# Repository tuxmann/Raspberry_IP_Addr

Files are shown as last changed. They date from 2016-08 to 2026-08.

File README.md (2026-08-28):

# Raspberry Pi IP Address Display

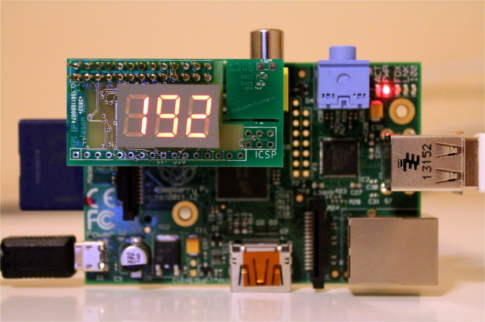
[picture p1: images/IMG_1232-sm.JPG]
Image of IP_Addr


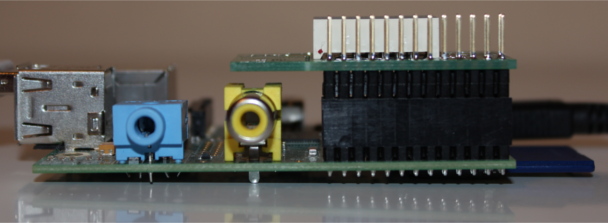
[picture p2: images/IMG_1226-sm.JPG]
Image of IP_Addr side


A hardware add-on that displays your Raspberry Pi's IP address on a 3-digit 7-segment LED display. Compatible with all Raspberry Pi models and other pin-compatible SBCs (Orange Pi, Banana Pi, Odroid, etc.).

## Quick Start

1. **Enable I2C and SPI:** `sudo raspi-config` → Interface Options
2. **Install:** `sudo apt install python3-smbus i2c-tools` (or `pip install smbus2`)
3. **Run:** `python3 hostip.py`
4. **Auto-start at boot:** `./deploy-to-pi.sh --install-service` (after deploying)

See **[docs/SETUP.md](docs/SETUP.md)** for the full setup guide, including ATtiny88 programming and the reset pin requirement.

## Hardware

- **Board:** ATtiny88 drives a 3-digit ELT-316 common-anode 7-segment display
- **Communication:** I2C at address 0x5A
- **Size:** Sits 0.6" (1.5cm) above the Pi; total height ~1" (2.5cm) with headers
- **Expansion:** P3 (left) and P4 (right) connectors bring out Port C & D (ADC, analog comparator, external interrupts)

## Features

- Power-on message ("rPI IP by JAY v1.1 GPL 3")
- Timeout message if no IP received within ~5 minutes
- Cycles through IP octets (e.g., 192 → 168 → 1 → 100)

## Climate node (DHT22, standalone)

The board can run **without a Pi** as a temperature/humidity display using a **DHT22** on header **P3 pin 1 (PC0)**.

- Firmware: [`climate-node-dht22/`](climate-node-dht22/)
- Setup, wiring, build, and flash: **[docs/CLIMATE_NODE.md](docs/CLIMATE_NODE.md)**

Shows °F (e.g. `78.3`) and humidity (e.g. `H38`), one sensor read every 6 seconds (3 s per value on the display). Optional photoresistor dimming on **P3 pin 2**; compile-time calibration offsets for temperature and humidity.

## Documentation

- [Setup Guide](docs/SETUP.md) — Pi IP display: installation, configuration, and flashing
- [Climate Node (DHT22)](docs/CLIMATE_NODE.md) — Standalone temp/humidity firmware
- [Releases](https://github.com/tuxmann/Raspberry_IP_Addr/releases) — Pre-built binaries and documents
- [Schematic](docs/Pi.IP.Addr.Schematic.pdf)

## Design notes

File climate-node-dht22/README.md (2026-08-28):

# climate-node-dht22

Standalone **ATtiny88** firmware for the Raspberry Pi IP Address board: read a **DHT22** and show **temperature** (°F) and **humidity** on the onboard 3-digit display—no Raspberry Pi required for normal operation.

**Full setup guide:** [docs/CLIMATE_NODE.md](../docs/CLIMATE_NODE.md)

## Quick reference

| Item | Value |
|---|---|
| DHT22 data pin | **PC0** — P3 pin 1 (U1 pin 23) |
| Ambient dim (optional) | **PC1** — P3 pin 2; or set `USE_PHOTOSENSOR 0` and `PWM_MANUAL` |
| Sample interval | 6 seconds (one bus transaction) |
| Display timing | 3 s temperature, then 3 s humidity per cycle |
| Build output | `bin/climate_node.hex` |
| DHT algorithm | Ported from [Adafruit DHT-sensor-library](https://github.com/adafruit/DHT-sensor-library) `DHT.cpp` |

## Wiring

- DHT22 **data** → P3 pin 1 (PC0)
- DHT22 **VCC** / **GND** → board power
- **4.7k–10k** pull-up: data → VCC
- Optional dimmer: **R1/R2** divider + LDR to **P3 pin 2** (PC1) — see [CLIMATE_NODE.md](../docs/CLIMATE_NODE.md)

Brightness is set in `src/ambient_dim.c`:

- `USE_PHOTOSENSOR 1` — LDR on PC1, sampled ~1 s (`ADC_BRIGHT` 200, `ADC_DARK` 450)
- `USE_PHOTOSENSOR 0` — ignore LDR; set `PWM_MANUAL` 0–255 (255 = full bright)

Calibration in `src/main.c` (whole display units):

- `TEMP_OFFSET` — added to displayed temperature (currently °F), e.g. `-2` makes `78.0` → `76.0`
- `HUMIDITY_OFFSET` — added to displayed %RH, e.g. `-5` makes `H38` → `H33`

## Build

```bash
make clean && make
```

### Debug: ambient ADC level + live dimming

Shows **raw ADC** or **PWM percent (0–100)** on the display. Switch with `DEBUG_SHOW_PWM_PCT` in `src/debug_brightness.c` (`1` = percent, `0` = raw ADC).

- `ADC_BRIGHT` — ADC at or below → PWM 255 (brightest)
- `ADC_DARK` — ADC at or above → PWM 20 (dimmes; tune `PWM_MIN`)

```bash
make debug
sudo make flash-debug
```

Cover the LDR: percent drops (dimmer). Shine light: percent rises toward **100**. Set `DEBUG_SHOW_PWM_PCT` to `0` to see raw ADC instead.

## Flash (on Raspberry Pi, board on GPIO for SPI programming)

```bash
sudo make flash
```

Slower ISP if needed: see [docs/CLIMATE_NODE.md](../docs/CLIMATE_NODE.md).

## Source layout

| File | Role |
|---|---|
| `src/main.c` | Main loop, calibration offsets, 6 s sample / 3 s per value |
| `src/debug_brightness.c` | Debug image: raw ADC or PWM % on display |
| `src/dht22.c` | DHT22 single-wire read (Adafruit-style timing) |
| `src/dht22.h` | Reading struct and API |
| `src/display_pwm.c` | Timer0 ISR PWM brightness for 7-seg multiplex |
| `src/ambient_dim.c` | Photoresistor ADC → PWM duty (optional hardware) |

## Third-party credit

DHT22 timing logic in `src/dht22.c` is derived from Adafruit’s **DHT-sensor-library** (MIT). See [github.com/adafruit/DHT-sensor-library](https://github.com/adafruit/DHT-sensor-library).

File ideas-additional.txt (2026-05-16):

Additional ideas that the daughter board can be used for.

Scrolling message — Reuse your power-on style messages; Pi sends which message index to show.
CPU load — Average load × 100 (e.g. 125 = 1.25) or “Idl” when idle.
RAM usage — Percent used (e.g. 67) or free MB.
CPU temperature — Pi sends CPU temp (e.g. 45, 52) over I2C; display shows “C45” or “52.” with decimal.
Disk usage — Root filesystem percent full (e.g. 42).
Wi‑Fi signal — RSSI as a number (e.g. -65 → “65” or “-65” if you allow minus).
Simple notifications — “Err”, “Ok”, “Run”, “Stp”, “Net”, “IP” for scripts or services.
Speedtest result — Download Mbps as 3 digits (e.g. 125).

Pi-hole stats — Queries today as hundreds (e.g. 523) or “dns” / “blk”.
Uptime — Days (e.g. 007) or hours (e.g. 123).
Countdown / timer — Pi sends remaining seconds; display counts down (e.g. 599 → 598…).
Clock — Hours and minutes as 3 digits (e.g. 143 = 1:43) or minutes:seconds.
Plex/streaming status — “Ply”, “Pau”, “0” when nothing playing.
VPN status — “On” / “Off” or tunnel number.
Hex/dec view — Show a value from the Pi in hex (e.g. 0x1A2) or decimal (e.g. 418).

With extra components 
BME280/DHT — Pi reads sensor, sends temp/humidity to display (e.g. 72° and 45% as “72” / “45” or “725”).
Button(s) on Port C/D — Cycle display mode (IP / temp / clock / message) or start/stop a timer.
Rotary encoder — Interrupts on Port D; show value or menu index (e.g. 001, 002).
Relay/GPIO status — Pi sends which outputs are on; display “1”, “2”, “12” or “On”/“Off”.
Distance (ultrasonic) — Pi talks to sensor, sends cm; display shows 0–999 cm.

Temperature sensor (e.g. thermistor/ADC) — P3/P4 ADC; ATtiny88 reads voltage, converts to °C/°F, shows on display (or Pi reads over I2C if you add that path).
Analog voltage monitor — ADC; show battery or supply voltage (e.g. 3.2 V as “3.2” or “320”).
Current sense — Current-sense amp to ADC; show mA or “0.5A” style reading.
Light level — LDR on ADC; display brightness level (0–99) or “LOW”/“HIG”.
Potentiometer — ADC; show 0–100 or use as volume/setpoint and display that.
PIR motion — Interrupt; show “On” when motion, “Off” or count of events.
Reed switch / door sensor — Interrupt; “OPn” / “Cld” or simple 0/1.
RTC (I2C) — Pi or ATtiny88 (if you add RTC on I2C) keeps time; display shows time without NTP when offline.
Multi-sensor dashboard — Button or timer cycles what’s shown: temp, humidity, light, IP, etc., with one sensor per “extra component” above.

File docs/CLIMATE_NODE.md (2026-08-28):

# Climate Node (DHT22) — Setup Guide

Standalone use of the Raspberry Pi IP Address board **without** a Raspberry Pi host: an ATtiny88 reads a **DHT22** sensor and shows **temperature** and **humidity** on the built-in 3-digit display.

Firmware lives in [`climate-node-dht22/`](../climate-node-dht22/).

## Hardware

| Connection | Detail |
|---|---|
| DHT22 data | **PC0** — **U1 pin 23**, header **P3 pin 1** |
| Ambient light (optional) | **PC1 (ADC1)** — **P3 pin 2** |
| DHT22 VCC / GND | Board power (see power section below) |
| Data pull-up | **4.7k–10k** from data to VCC (required) |

**Do not use** pins already used by the 7-segment display, I2C (SDA/SCL), SPI (ISP), or UART if you may add those interfaces later.

### Optional photoresistor dimming (P3 pin 2)

Divider from **VCC** to **GND** with tap to **PC1**:

```text
VCC ---- R1 ----+---- PC1 (P3 pin 2)
                |
                +---- R2 ---- GND
                |
                LDR (optional, to GND, parallel with R2)
```

- Install **R1** and **R2** on boards that use dimming.
- **Bright room** → lower ADC → brighter display. **Dark room** → higher ADC → dimmer display.
- In `src/ambient_dim.c`:
  - `USE_PHOTOSENSOR 1` — read LDR once per second (`ADC_BRIGHT` **200**, `ADC_DARK` **450**, same as debug).
  - `USE_PHOTOSENSOR 0` — no LDR; set `PWM_MANUAL` **0–255** (255 = full brightness).

Tune `ADC_BRIGHT`, `ADC_DARK`, `PWM_MIN`, and `PWM_MANUAL` in `src/ambient_dim.c`.

### Standalone power (no Pi)

- Feed **5 V** and ground from USB (or similar).
- Many builds tie **P1 pins 1, 2, and 4** as 5 V tie points and use **P1 ground pins** (e.g. 6, 9, 14, 20) for return.
- Confirm your board’s actual rail (3.3 V vs 5 V for the MCU) matches how you power the DHT22.

### Programming (Pi + SPI)

To **flash** firmware, stack the board on a Raspberry Pi with **SPI enabled** and use the same **linuxspi** wiring as the original IP-display project (reset **not** held to ground). See [SETUP.md](SETUP.md) §7.

## Display behavior

| Phase | Display | Duration |
|---|---|---|
| Power-up | `rdy` | 2 s |
| Each 6 s cycle | Temperature (°F), then humidity | 3 s each |
| Read failed (including disconnected sensor) | `Err` | Until next good read; replaces last values on screen |

**Temperature (°F)**

- Below 100 °F: one decimal (e.g. `78.3`)
- 100 °F and above: integer only (e.g. `104`)

**Humidity**

- `H` + two digits (e.g. `H38` for 38%)

**Calibration** (`src/main.c`):

- `TEMP_OFFSET` — whole degrees of the displayed scale (currently °F). Example: `-2` shows `76.0` instead of `78.0`.
- `HUMIDITY_OFFSET` — whole percent RH. Example: `-5` shows `H33` instead of `H38`.

Sensor is polled **once every 6 seconds** (`SAMPLE_PERIOD_MS` in `src/main.c`). Temperature and humidity each stay on screen for **3 seconds** (`SHOW_TEMP_MS`). DHT22 needs quiet time between reads; do not poll faster than about every 2 s.

**Brightness:** Timer0 ISR software PWM (`src/display_pwm.c`). With `USE_PHOTOSENSOR 1`, duty follows ambient ADC (**200** bright → **450** dark) about once per second. With `USE_PHOTOSENSOR 0`, duty is fixed at `PWM_MANUAL`.

## DHT driver

Bit timing is ported from **[Adafruit DHT-sensor-library](https://github.com/adafruit/DHT-sensor-library)** (`DHT.cpp`). The AVR driver is in `src/dht22.c` (cycle-count pulse compare, same algorithm).

## Build and flash

### On the Raspberry Pi (recommended)

```bash
cd ~/Raspberry_IP_Addr/climate-node-dht22
make clean && make
sudo make flash
```

If avrdude reports *device not responding*, use a slower ISP clock:

```bash
sudo avrdude -c linuxspi -P /dev/spidev0.0:/dev/gpiochip0 -p t88 -B 125kHz \
  -U flash:w:bin/climate_node.hex:i
```

Or slower:

```bash
sudo avrdude -c linuxspi -P /dev/spidev0.0:/dev/gpiochip0 -p t88 -B 50kHz \
  -U flash:w:bin/climate_node.hex:i
```

### On a development PC (compile only)

```bash
sudo apt install gcc-avr avr-libc
cd climate-node-dht22
make
```

Copy `bin/climate_node.hex` to the Pi and flash with `sudo make flash` or the `avrdude` line above.

### Deploy source from your PC

```bash
rsync -avz --exclude '.git' ./ jason@raspberrypi.local:~/Raspberry_IP_Addr/
```

Or from repo root: `./deploy-to-pi.sh` (syncs the whole tree, including `climate-node-dht22/`).

> **Note:** `deploy-to-pi.sh` option “build + flash” still targets the root **`show_ip`** firmware. For the climate node, run `make` / `sudo make flash` inside **`climate-node-dht22/`** on the Pi.

## Debug firmware (ADC level + live dimming)

Build and flash the debug image to tune **ADC_BRIGHT** / **ADC_DARK** in `src/debug_brightness.c` (defaults **200** / **450**, same as `src/ambient_dim.c`):

```bash
cd ~/Raspberry_IP_Addr/climate-node-dht22
make debug
sudo make flash-debug
```

Display shows **PWM percent 0–100** (`DEBUG_SHOW_PWM_PCT 1`) or **raw ADC** (`0`). Brightness tracks the reading in real time.

## Troubleshooting

| Symptom | Things to check |
|---|---|
| `Err` on display | Data on **P3 pin 1**, pull-up, common GND; failed read shows within ~6 s; reflash latest hex |
| `rdy` forever | No successful read yet; wiring, power, sensor type (DHT22 not DHT11) |
| Wrong values | `F_CPU` in Makefile must match ATtiny fuse clock (default **8 MHz**) |
| avrdude no response | Board on Pi header, SPI on, reset not grounded; try `-B 125kHz` or `-B 50kHz` |
| Scope shows frequent DHT starts | Old firmware with retry bursts; use current build (one read per 6 s) |
| Display always dim / always bright | `USE_PHOTOSENSOR` / `PWM_MANUAL`; or `ADC_BRIGHT` / `ADC_DARK` in `ambient_dim.c` |
| No dimming with LDR installed | Set `USE_PHOTOSENSOR 1`; confirm LDR on **P3 pin 2** |

## Related docs

- [Main setup (Pi IP display)](SETUP.md)
- [Project README](../README.md)
- [climate-node-dht22 README](../climate-node-dht22/README.md)

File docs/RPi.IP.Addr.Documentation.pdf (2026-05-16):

# Pi IP Address add-on board for the Raspberry PI

By Jason Mann
Last updated: March 7th, 2015

Hardware License: CC BY-SA Software License: GPL V3

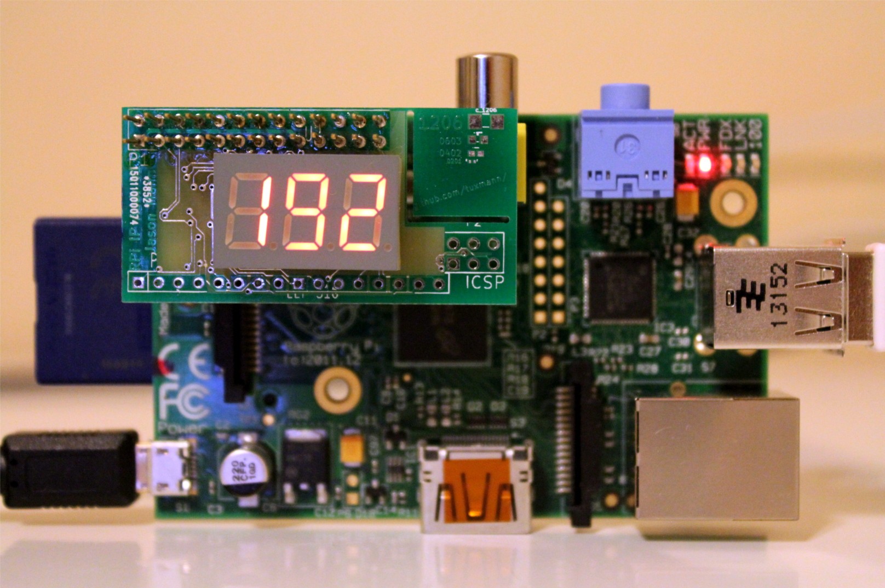
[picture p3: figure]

The Pi IP Address board makes it easier to know the IP Address of your Raspberry Pi when it's connected to a network. This board is compatible with all Raspberry Pi computers as well as other single board computers that are pin compatible. The board sits 0.6 inches (or 1.5cm) above the Raspberry Pi. The tops of the header pins go up to 1 inch (or 2.5cm). The add-on board uses an ATtiny88 by Atmel to drive a 3 digit 7 segment LED display. There are 16 pins from the ATtiny88 that are brought out to the edge of the board to give the user the opportunity to increase the functionality of the add on board.

## Setting up the Raspberry Pi

Ensure that the Raspberry Pi is powered off before installing the add-on board. Install the add on board so that all of the 26 original pins are connected as seen in the picture below. Take care to not offset the pins or it may cause serious damage to the Pi IP Address add-on board or your Raspberry Pi. Plug in the Raspberry Pi and allow it to boot up. You will notice that the Pi IP Address board is counting from 001 to 004. This is acceptable because it hasn't yet received the IP address from the Raspberry Pi.

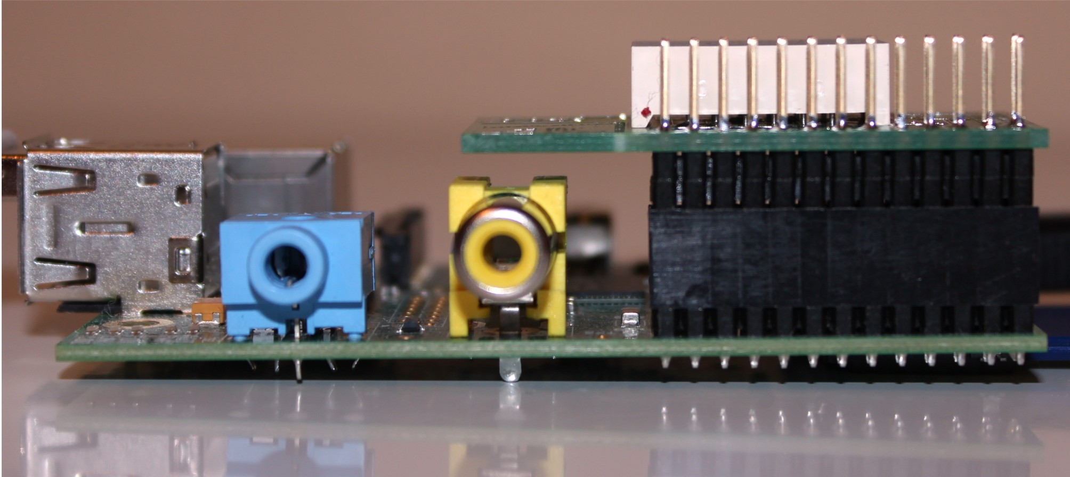
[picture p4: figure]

Log in to the Raspberry Pi. I will be logging in under the username of pi. Replace 'pi' with your username if needed.

Install the required software to communicate with the IP Aand clone the repository
sudo aptget update && sudo aptget install git pythonsmbus i2ctools
git clone https://github.com/tuxmann/Raspberry_IP_Addr.git

Install communications software to talk to the Pi IP Address add-on board by editing the modules file.
sudo nano /etc/modules
Add these lines to the modules file:
i2cbcm2708
i2cdev
Ctrl + X and save the file

Enable the I2C communcation
sudo nano /etc/modprobe.d/raspiblacklist.conf Comment out this line by adding a '#' character
#blacklist i2cbcm2708

Ctrl + X and save the file

Gain root access and add the python script to run at startup
sudo su
crontab e
Add this line to the end of the file (change pi to username you're logged in as):
@reboot python /home/pi/Raspberry_IP_Addr/hostip.py

Reboot the Raspberry Pi
sudo reboot

Once the Raspberry Pi finishes rebooting and if it's plugged into a network connection (wireless or not) it will display the IP address. The display will show “255.000.255.000” if it's not connected to a network. If wireless and wired are both connected, it will not display either.

To verify that the program is working correctly, you can run the command below. Navigate to the directory that holds the hostip.py file.
cd /path/to/hostip.py
sudo python hostip.py

## Programming the add-on board

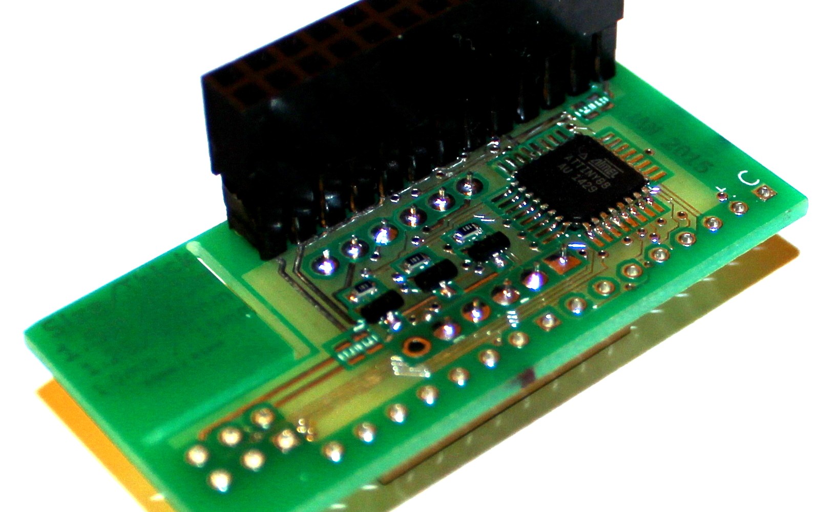
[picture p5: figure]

If you want to reprogram the Pi IP Address add-on board to do more (or less) than what I programmed it for, these are the instructions that will get you up & running. You will also need four wires connected to the 6 pin ISCP port in order to program the Pi IP Address.

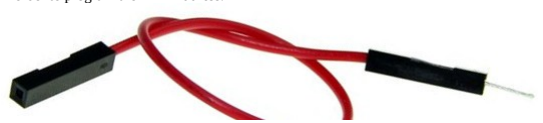
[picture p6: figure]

Setting up the Raspberry Pi as an AVR Programmer.
This assumes that you don't already have the avrdude program alread installed. If you already have a version installed, you may experience problems programming the ATtiny88.

Install necessary software to compile the code from Kevin Cuzner's repository.
sudo aptget install bison autoconf flex

Remove the SPI interface from the raspi-blacklist.conf by commenting it out
sudo nano /etc/modprobe.d/raspiblacklist.conf
#blacklist spibcm2708

Ctrl + X and save the file

Clone the repository
git clone https://github.com/kcuzner/avrdude.git

Run the “./bootstrap” script
cd avrdude/avrdude/
./bootstrap
./configure (Ensure that “ENABLED linuxspi” shows up at the bottom)
make
sudo make install

Verifying that linuxspi is a valid programmer
avrdude c ?type

Verify that you can reprogram the ATtiny88 by connecting the wires and running the command below. Use wires that have a male connection on one side and female on the opposite side. Be careful to connect the wires to their intended pins and vias in order to prevent damage. The GND ground wire will connect to the RESET pin of the ATtiny88 and it will be ready to program. Once you're finished programming, disconnect the ground wire to let the ATtiny88 out of reset. The sample program will count down from four instead of counting up to four.
sudo avrdude c linuxspi p t88 -P /dev/spidev0.0 -U flash:w:pi_wohs.hex

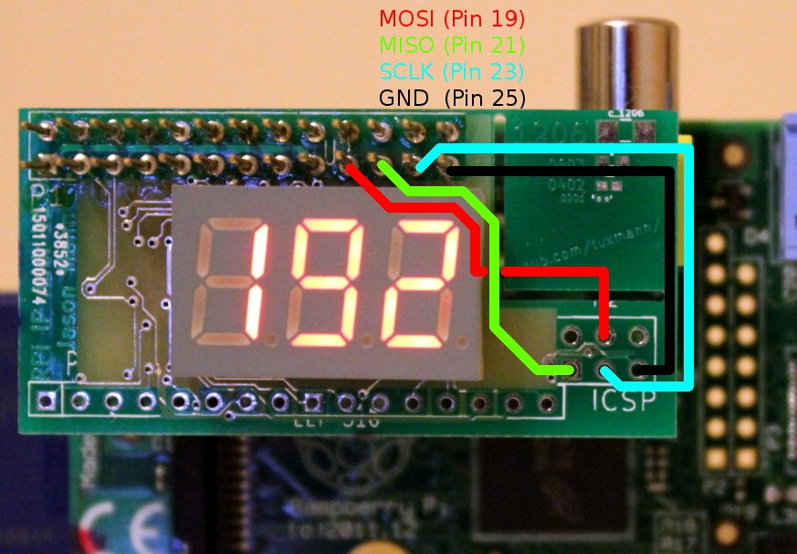
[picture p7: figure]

Programming commands
For my programming setup, I used Geany & then I pushed the final .hex file to the Raspberry Pi with Filezilla. Once the file is on the Raspberry Pi, ground the reset line on the ICSP port and then run the command below.
sudo avrdude c linuxspi p t88 -P /dev/spidev0.0 -U flash:w:your_file.hex

Geany build setup:
Choose Build and then Set Build Commands and put in lines below as seen in the screenshot.
avrgcc mmcu=attiny88 -Wall -Os o %e.elf %f
avrobjcopy j .text j .data -O ihex %e.elf %e.hex

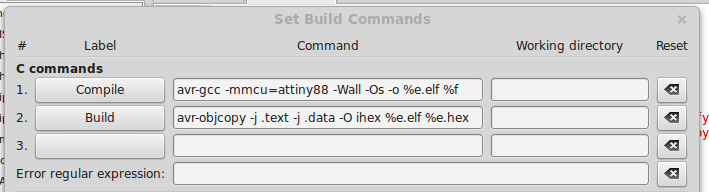
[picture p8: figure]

Filezilla SFTP setup:
Go to File and choose Site Manager and adjust the settings to match the screenshot.

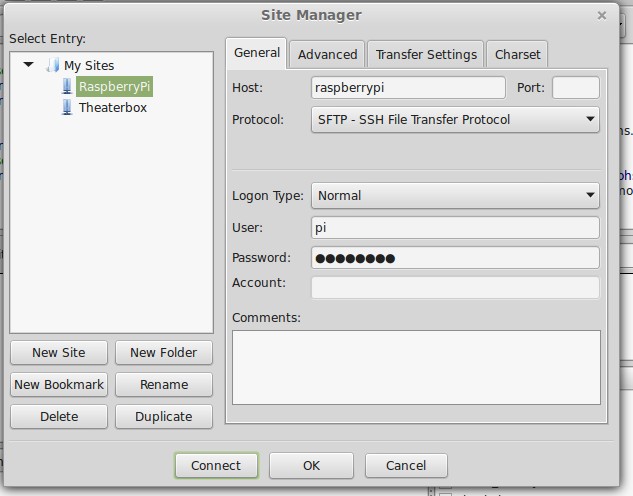
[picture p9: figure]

Resources
http://www.atmel.com/devices/attiny88.aspxhttp://kevincuzner.com/2013/05/27/raspberry-pi-as-an-avr-programmer/http://pengu.student.utwente.nl/wordpress/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

To Do:
Turn the install instructions into a bash script Add the idle animations
Comment & Clean up code
Documentation
Create a BOM
Ensure that Pi IP Address cycle times are slow enough.

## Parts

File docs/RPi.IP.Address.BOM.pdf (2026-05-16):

Sheet1

Page 1

| Raspberry PI IP Address Bill Of Materials | Rev: A
Reference Designator | Part Number | Description | Qty | Unit of Meas | Notes / Supplier
C1, C2, C3, C4 | C0603C104K5RACTU | Kemet Multilayer Ceramic Capacitors MLCC – 0.1 uF | 4 | 4 | Mouser
P1 | Adafruit PID 1112 | Stacking Header for Raspberry Pi - 2x13 Extra Tall. 13.6mm tall | 1 | 1 | Adafruit
Q1, Q2, Q3 | BC847-T | Rectron Transistors Bipolar - BJT | 3 | 3 | Mouser
R1, R2, R3 | CRCW060310K0JNEA | Vishay Thick Film Resistors – 10k Ohms | 3 | 3 | Mouser
RP1, RP2 | 741C083181JP | CTS Resistor Networks & Arrays – 180 Ohms | 2 | 2 | Mouser
U1 | ATTINY88-AU | Atmel 8-bit Microcontrollers – MCU. 8K Flash, 256 Bytes | 1 | 1 | Mouser
U2 | ELT-316SURWA/S530-A3 | EVERLIGHT 0.36" Triple Digit | 1 | 1 | Mouser

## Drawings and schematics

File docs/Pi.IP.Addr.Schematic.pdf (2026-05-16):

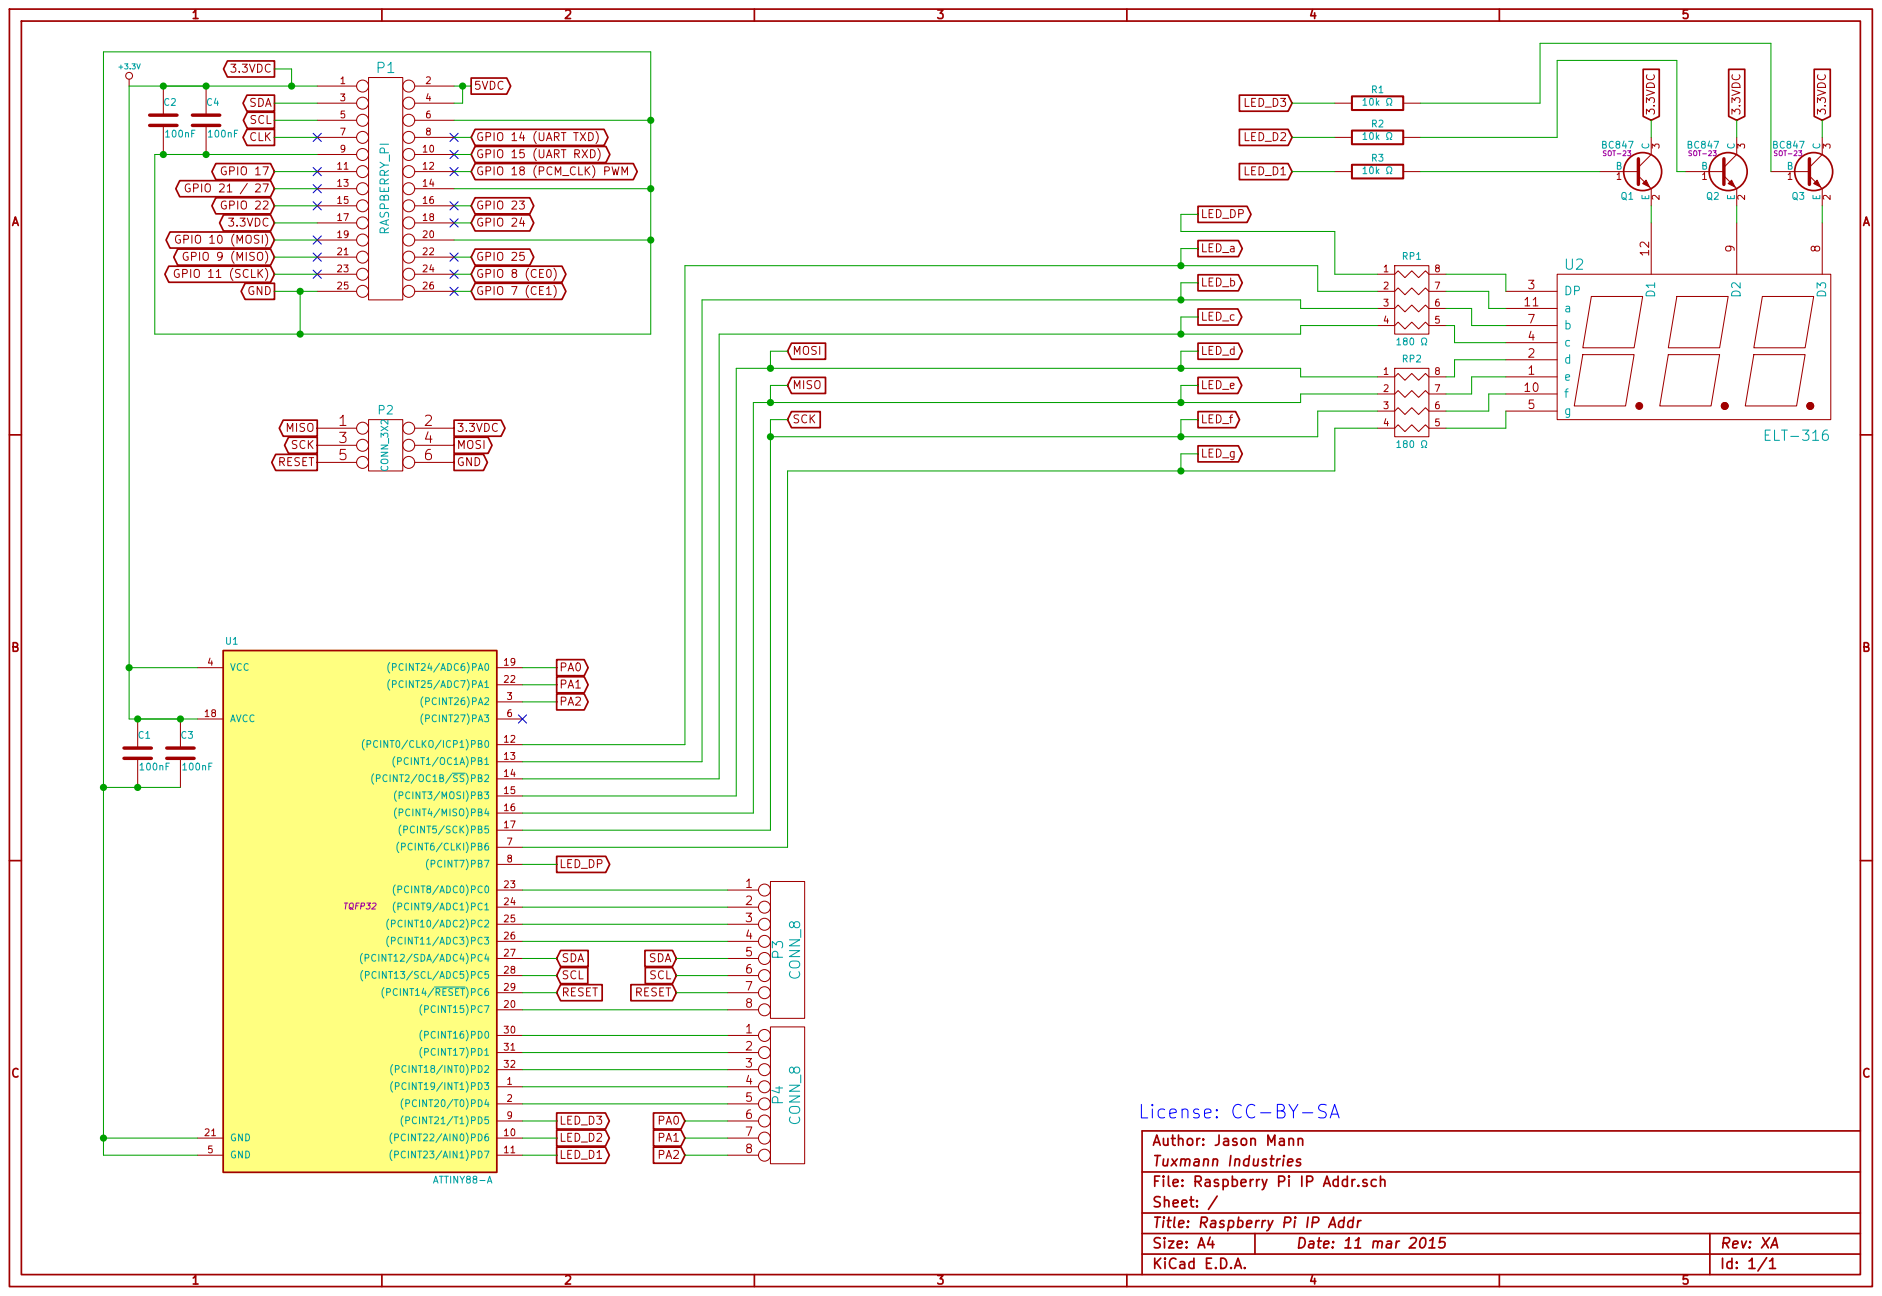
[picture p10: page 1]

SCL CLK GPIO 21 / 27 GPIO 17 GPIO 22

Sheet: / Tuxmann Industries Author: Jason Mann

File: Raspberry Pi IP Addr.sch

Title: Raspberry Pi IP Addr

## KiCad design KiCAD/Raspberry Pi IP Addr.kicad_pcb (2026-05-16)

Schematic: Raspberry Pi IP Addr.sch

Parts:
C1, C2, C3, C4: 100nF
P1: RASPBERRY_PI
P2: CONN_3X2
P3, P4: CONN_8
Q1, Q2, Q3: BC847; SOT-23
R1, R2, R3: 10k Ω
RP1, RP2: 180 Ω
U1: ATTINY88-A; TQFP32
U2: ELT-316

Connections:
3.3VDC: C1.1, C2.1, C3.1, C4.1, P1.1, P1.17, P2.2, Q1.3 (C), Q2.3 (C), Q3.3 (C), U1.4 (VCC), U1.18 (AVCC)
5VDC: P1.2, P1.4
GND: C1.2, C2.2, C3.2, C4.2, P1.6, P1.9, P1.14, P1.20, P1.25, P2.6, U1.5 (GND), U1.21 (GND)
LED_D1: R3.1, U1.11 ((PCINT23/AIN1)PD7)
LED_D2: R2.1, U1.10 ((PCINT22/AIN0)PD6)
LED_D3: R1.1, U1.9 ((PCINT21/T1)PD5)
LED_DP: RP1.1, U1.8 ((PCINT7)PB7)
LED_a: RP1.2, U1.12 ((PCINT0/CLKO/ICP1)PB0)
LED_b: RP1.3, U1.13 ((PCINT1/OC1A)PB1)
LED_c: RP1.4, U1.14 ((PCINT2/OC1B/~SS~)PB2)
LED_d: P2.4, RP2.1, U1.15 ((PCINT3/MOSI)PB3)
LED_e: P2.1, RP2.2, U1.16 ((PCINT4/MISO)PB4)
LED_f: P2.3, RP2.3, U1.17 ((PCINT5/SCK)PB5)
LED_g: RP2.4, U1.7 ((PCINT6/CLKI)PB6)
unnamed: Q1.2 (E), U2.12 (D1)
unnamed: Q2.2 (E), U2.9 (D2)
unnamed: Q3.2 (E), U2.8 (D3)
unnamed: Q3.1 (B), R1.2
unnamed: Q1.1 (B), R3.2
unnamed: Q2.1 (B), R2.2
unnamed: P3.3, U1.25 ((PCINT10/ADC2)PC2)
unnamed: P3.2, U1.24 ((PCINT9/ADC1)PC1)
unnamed: P3.1, U1.23 ((PCINT8/ADC0)PC0)
unnamed: P3.8, U1.20 ((PCINT15)PC7)
unnamed: P3.4, U1.26 ((PCINT11/ADC3)PC3)
unnamed: P4.5, U1.2 ((PCINT20/T0)PD4)
unnamed: P4.4, U1.1 ((PCINT19/INT1)PD3)
unnamed: P4.3, U1.32 ((PCINT18/INT0)PD2)
unnamed: P4.2, U1.31 ((PCINT17)PD1)
unnamed: P4.1, U1.30 ((PCINT16)PD0)
unnamed: RP1.8 (R1), U2.3 (DP)
unnamed: RP2.5 (R4), U2.5 (g)
unnamed: RP2.6 (R3), U2.10 (f)
unnamed: RP2.7 (R2), U2.1 (e)
unnamed: RP2.8 (R1), U2.2 (d)
unnamed: RP1.7 (R2), U2.11 (a)
unnamed: RP1.6 (R3), U2.7 (b)
unnamed: RP1.5 (R4), U2.4 (c)
PA0: P4.6, U1.19 ((PCINT24/ADC6)PA0)
PA1: P4.7, U1.22 ((PCINT25/ADC7)PA1)
PA2: P4.8, U1.3 ((PCINT26)PA2)
RESET: P2.5, P3.7, U1.29 ((PCINT14/~RESET~)PC6)
SCL: P1.5, P3.6, U1.28 ((PCINT13/SCL/ADC5)PC5)
SDA: P1.3, P3.5, U1.27 ((PCINT12/SDA/ADC4)PC4)

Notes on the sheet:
License: CC-BY-SA

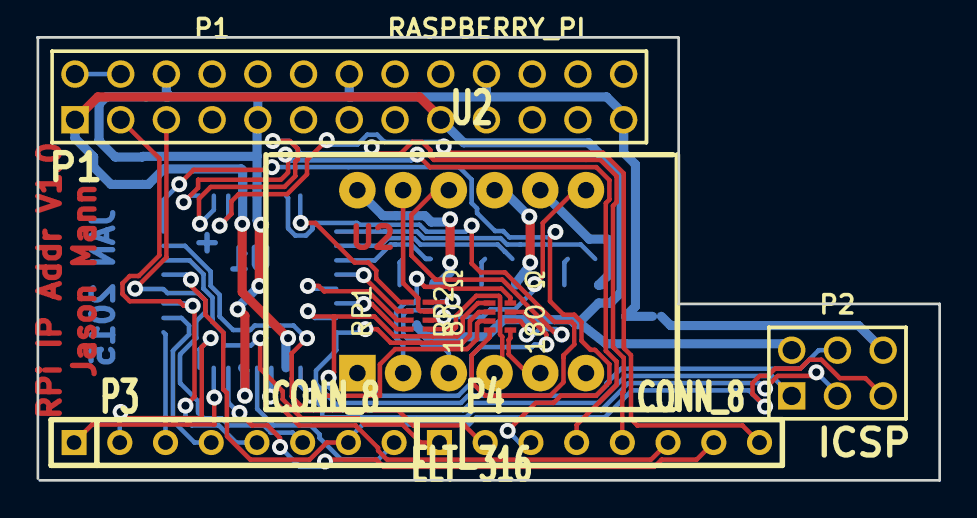
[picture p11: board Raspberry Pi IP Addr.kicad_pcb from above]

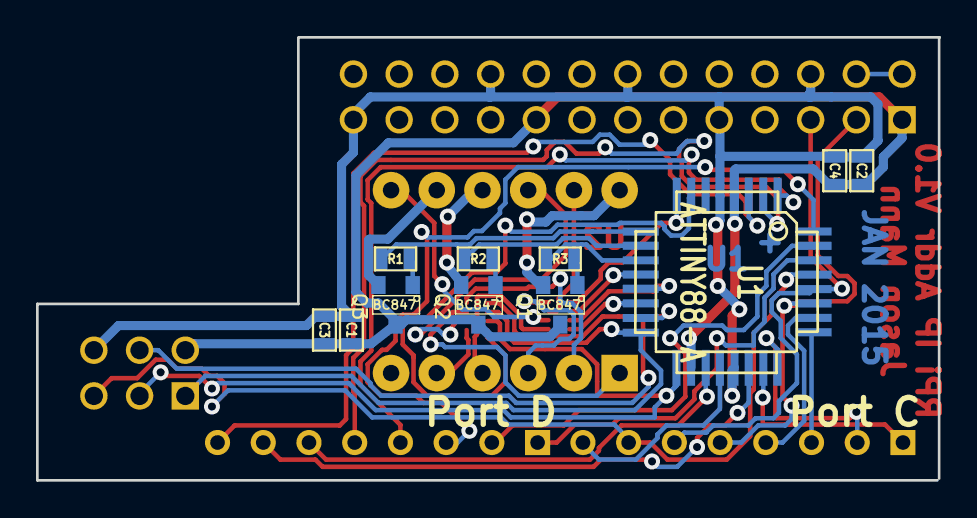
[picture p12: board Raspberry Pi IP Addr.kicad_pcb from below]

Board: 2 copper layers, 50.1 x 24.6 mm, 18 parts (11 on the bottom side), 44 nets.

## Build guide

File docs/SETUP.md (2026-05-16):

# Raspberry Pi IP Address Display - Setup Guide

This guide covers setting up the Pi IP Address board on a Raspberry Pi, including running the Python script and programming the ATtiny88 firmware.

## Hardware Requirements

- Raspberry Pi (any model with 40-pin GPIO)
- Pi IP Address add-on board (ATtiny88 + 3-digit 7-segment display)
- Board connected via GPIO header

## 1. Enable I2C and SPI

```bash
sudo raspi-config
```

Navigate to: **Interface Options** → **I2C** → **Enable**  
Then: **Interface Options** → **SPI** → **Enable**

Reboot after enabling.

## 2. Install Dependencies

### Python script (hostip.py)

```bash
# Option A: System packages (Raspberry Pi OS)
sudo apt update
sudo apt install python3-smbus i2c-tools

# Option B: Use smbus2 (recommended for broader compatibility)
pip install smbus2
```

### AVR programming (for flashing ATtiny88)

```bash
sudo apt install avrdude
```

> **Note:** Some Raspberry Pi OS versions may ship avrdude without `linuxspi` support. If `avrdude -c linuxspi` fails, you may need to [build avrdude from source](https://github.com/avrdudes/avrdude) with linuxspi enabled.

## 3. Verify I2C Board Detection

```bash
i2cdetect -y 1
```

You should see `5a` in the output when the board is connected. On older Pi models, try `-y 0` instead.

## 4. Run the IP Display Script

```bash
# From the project directory
python3 hostip.py
```

The script will:
- Detect the I2C bus with the board (0x5A)
- Read the Pi's IP address
- Send it to the display every 120 seconds

## 5. Run at Startup (Optional)

A systemd service runs the script automatically after boot:

```bash
# From your development machine, after deploying:
./deploy-to-pi.sh --install-service

# Or manually on the Pi:
sudo cp ~/Raspberry_IP_Addr/hostip.service /etc/systemd/system/
sudo systemctl daemon-reload
sudo systemctl enable hostip
sudo systemctl start hostip
```

Useful commands:
- `sudo systemctl status hostip` — check status
- `sudo systemctl stop hostip` — stop the service
- `sudo journalctl -u hostip -f` — view logs

## 6. Build Firmware (on development machine)

If you need to rebuild the ATtiny88 firmware:

```bash
# Install avr-gcc (Ubuntu/Debian)
sudo apt install gcc-avr avr-libc

# Build
make
```

This produces `bin/show_ip.hex`.

## 7. Flash Firmware to ATtiny88 (on Raspberry Pi)

The board must be connected to the Pi's SPI pins (CLK, MISO, MOSI, GND). **Important:** The ATtiny88 reset pin must be connected to a GPIO (e.g., GPIO 25 via gpiochip0), not ground—otherwise the chip cannot be programmed and I2C will not respond.

Flash with:

```bash
avrdude -c linuxspi -p t88 -P /dev/spidev0.0:/dev/gpiochip0 -B 10 -U flash:w:show_ip.hex:i
```

Or from the project root:
```bash
make flash
```

The `:i` suffix (or `-U flash:w:file.hex:i` in Intel hex format) ensures proper parsing.

## 8. Remote Setup via SSH

### One-time: Enable SSH key login (optional)

```bash
ssh-copy-id jason@raspberrypi.local
# Enter Pi password when prompted; future logins won't need it
```

### Deploy and run from your development machine

```bash
# Copy project to Pi
scp -r /path/to/Raspberry_IP_Addr jason@raspberrypi.local:~/

# SSH in and run
ssh jason@raspberrypi.local "cd Raspberry_IP_Addr && python3 hostip.py"
```

Or use the deploy script: `./deploy-to-pi.sh` (defaults to jason@raspberrypi.local)

### Build and flash firmware from your development machine

Deploy source, compile on the Pi, and flash in one step (avoids flashing stale hex):

```bash
./build-and-flash-on-pi.sh
```

The Pi needs build tools: `sudo apt install gcc-avr avr-libc avrdude`

## 9. Climate node firmware (DHT22, optional)

To use the board as a **standalone** temp/humidity display (no `hostip.py`), build and flash the sub-project on the Pi:

```bash
cd ~/Raspberry_IP_Addr/climate-node-dht22
make clean && make
sudo make flash
```

See **[CLIMATE_NODE.md](CLIMATE_NODE.md)** for DHT22 wiring (P3 pin 1), power, display format, and troubleshooting.

## Troubleshooting

| Issue | Solution |
|---|---|
| "Pi IP Address board not detected" | Enable I2C in raspi-config, check connections. Ensure reset pin is **not** tied to ground. |
| Board at 0x5A not found / avrdude fails | Reset pin must connect to GPIO 25 (or gpiochip0 reset), not GND. With reset grounded, the ATtiny88 cannot run or respond on I2C. |
| "Permission denied" on /dev/i2c-* | Add user to i2c group: `sudo usermod -aG i2c $USER` |
| avrdude "linuxspi" not found | Build avrdude from source or use USBasp programmer |
| Wrong IP displayed | `hostname --all-ip-addresses` returns first interface; use `ip addr` to verify |

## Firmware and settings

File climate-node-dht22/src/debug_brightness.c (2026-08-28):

/*
 * Debug firmware: show ADC or PWM% on PC1 and dim via Timer0 PWM.
 * DEBUG_SHOW_PWM_PCT 1 = duty 0-100, 0 = raw ADC.
 * Tune ADC_BRIGHT / ADC_DARK / PWM_MIN below, reflash.
 *
 * Build:  make debug
 * Flash:  sudo make flash-debug
 */

#ifndef F_CPU
#define F_CPU 8000000UL
#endif

#include <avr/io.h>
#include <stdint.h>

#include "display_pwm.h"

#define ADC_BRIGHT          200U
#define ADC_DARK            450U
#define PWM_MAX             255U
#define PWM_MIN             20U

/* 0 = show raw ADC (0-1023), 1 = show PWM duty as 0-100 percent. */
#define DEBUG_SHOW_PWM_PCT  1

#define AMBIENT_ADC_CHANNEL 1U
#define SAMPLE_MS           1000U

static uint8_t char_led[3];

static uint8_t digit_to_segment(uint8_t v)
{
    switch (v) {
        case 0: return 0xC0;
        case 1: return 0xF9;
        case 2: return 0xA4;
        case 3: return 0xB0;
        case 4: return 0x99;
        case 5: return 0x92;
        case 6: return 0x82;
        case 7: return 0xF8;
        case 8: return 0x80;
        case 9: return 0x90;
        default: return 0xFF;
    }
}

static void adc_init_pc1(void)
{
    DDRC &= (uint8_t)~(1U << PC1);
    PORTC &= (uint8_t)~(1U << PC1);
    ADMUX = (uint8_t)((1U << REFS0) | (AMBIENT_ADC_CHANNEL & 0x0FU));
    ADCSRA = (1U << ADEN) | (1U << ADPS2) | (1U << ADPS1);
}

static uint16_t adc_read_pc1(void)
{
    uint8_t i;
    uint32_t sum = 0;

    ADMUX = (uint8_t)((1U << REFS0) | (AMBIENT_ADC_CHANNEL & 0x0FU));
    for (i = 0; i < 4U; i++) {
        ADCSRA |= (1U << ADSC);
        while (ADCSRA & (1U << ADSC)) {
        }
        sum += (uint16_t)ADC;
    }
    return (uint16_t)(sum / 4U);
}

static uint8_t map_adc_to_pwm(uint16_t adc)
{
    int32_t pwm;

    if (adc <= ADC_BRIGHT) {
        return PWM_MAX;
    }
    if (adc >= ADC_DARK) {
        return PWM_MIN;
    }

    pwm = (int32_t)PWM_MAX -
          ((int32_t)(adc - ADC_BRIGHT) * (PWM_MAX - PWM_MIN)) /
          (int32_t)(ADC_DARK - ADC_BRIGHT);
    return (uint8_t)pwm;
}

static void set_number_display(uint16_t value)
{
    if (value > 999U) {
        value = 999U;
    }

    char_led[0] = digit_to_segment((uint8_t)(value / 100U));
    char_led[1] = digit_to_segment((uint8_t)((value / 10U) % 10U));
    char_led[2] = digit_to_segment((uint8_t)(value % 10U));

    if (value < 100U) {
        char_led[0] = 0xFF;
    }
    if (value < 10U) {
        char_led[1] = 0xFF;
    }
}

int main(void)
{
    uint16_t last_ms = 0;
    uint16_t adc = 0U;

    display_pwm_init();
    adc_init_pc1();
    set_number_display(0U);
    display_pwm_set_segments(char_led[0], char_led[1], char_led[2]);
    last_ms = display_pwm_millis();

    while (1) {
        uint16_t now = display_pwm_millis();

        if ((uint16_t)(now - last_ms) >= SAMPLE_MS) {
            uint8_t pwm;

            last_ms = now;
            adc = adc_read_pc1();
            pwm = map_adc_to_pwm(adc);
            display_pwm_set_brightness(pwm);
#if DEBUG_SHOW_PWM_PCT
            set_number_display((uint16_t)(((uint16_t)pwm * 100U) / PWM_MAX));
#else
            set_number_display(adc);
#endif
            display_pwm_set_segments(char_led[0], char_led[1], char_led[2]);
        }
    }
}

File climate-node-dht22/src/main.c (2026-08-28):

#ifndef F_CPU
#define F_CPU 8000000UL
#endif

#include <avr/io.h>
#include <stdint.h>

#include "ambient_dim.h"
#include "display_pwm.h"
#include "dht22.h"

/*
 * DHT22: wait at least 2 s between reads; we use 6 s.
 * One start pulse per period (no rapid retries).
 */
#define SAMPLE_PERIOD_MS 6000U
#define SHOW_TEMP_MS     3000U
#define STARTUP_DELAY_MS 2000U

/*
 * Calibration: whole display units (not tenths).
 * TEMP_OFFSET is applied after C→F conversion (display is °F today), so
 * -2 makes 78.0F show as 76.0F. If you later display °C, the same define
 * would subtract 2 °C.
 * HUMIDITY_OFFSET is whole percent RH points (-5 makes H38 → H33).
 */
#define TEMP_OFFSET      -1
#define HUMIDITY_OFFSET   0

static uint8_t char_led[3];

static uint8_t digit_to_segment(uint8_t v)
{
    switch (v) {
        case 0: return 0xC0;
        case 1: return 0xF9;
        case 2: return 0xA4;
        case 3: return 0xB0;
        case 4: return 0x99;
        case 5: return 0x92;
        case 6: return 0x82;
        case 7: return 0xF8;
        case 8: return 0x80;
        case 9: return 0x90;
        default: return 0xFF;
    }
}

static uint8_t letter_to_segment(char c)
{
    switch (c) {
        case 'H': return 0x89;
        case 'E': return 0x86;
        case '-': return 0xBF;
        case 'r': return 0xAF;
        case 'd': return 0xA1;
        case 'y': return 0x91;
        default: return 0xFF;
    }
}

static void set_ready_display(void)
{
    char_led[0] = letter_to_segment('r');
    char_led[1] = letter_to_segment('d');
    char_led[2] = letter_to_segment('y');
}

static void set_error_display(void)
{
    char_led[0] = letter_to_segment('E');
    char_led[1] = letter_to_segment('r');
    char_led[2] = letter_to_segment('r');
}

static void set_temperature_display(int16_t temp_c_tenths)
{
    /* Convert to °F tenths, then apply whole-degree calibration. */
    int16_t temp_f_tenths = (int16_t)(((int32_t)temp_c_tenths * 9 + 25) / 5 + 320);
    temp_f_tenths = (int16_t)(temp_f_tenths + ((int16_t)TEMP_OFFSET * 10));

    if (temp_f_tenths < 0) {
        char_led[0] = letter_to_segment('-');
        char_led[1] = digit_to_segment((uint8_t)((-temp_f_tenths / 10) % 10));
        char_led[2] = digit_to_segment((uint8_t)((-temp_f_tenths) % 10));
        return;
    }

    if (temp_f_tenths >= 1000) {
        uint16_t rounded = (uint16_t)((temp_f_tenths + 5) / 10);
        if (rounded > 999U) {
            rounded = 999U;
        }

        char_led[0] = digit_to_segment((uint8_t)(rounded / 100U));
        char_led[1] = digit_to_segment((uint8_t)((rounded / 10U) % 10U));
        char_led[2] = digit_to_segment((uint8_t)(rounded % 10U));
        return;
    }

    {
        uint8_t tens = (uint8_t)((temp_f_tenths / 100) % 10);
        uint8_t ones = (uint8_t)((temp_f_tenths / 10) % 10);
        uint8_t tenths = (uint8_t)(temp_f_tenths % 10);

        char_led[0] = (tens == 0U) ? 0xFF : digit_to_segment(tens);
        char_led[1] = digit_to_segment(ones) & 0x7F;
        char_led[2] = digit_to_segment(tenths);
    }
}

static void set_humidity_display(uint16_t humidity_tenths)
{
    int16_t humidity = (int16_t)((humidity_tenths + 5U) / 10U) + (int16_t)HUMIDITY_OFFSET;

    if (humidity < 0) {
        humidity = 0;
    }
    if (humidity > 99) {
        humidity = 99;
    }

    char_led[0] = letter_to_segment('H');
    char_led[1] = digit_to_segment((uint8_t)(humidity / 10));
    char_led[2] = digit_to_segment((uint8_t)(humidity % 10));
}

int main(void)
{
    uint16_t last_ms;
    uint16_t elapsed_since_sample = 0;
    uint16_t elapsed_in_cycle = 0;
    uint16_t startup_ms = 0;

    uint16_t humidity_tenths = 0;
    int16_t temperature_tenths_c = 0;
    uint8_t have_reading = 0;
    uint8_t last_read_failed = 0;

    display_pwm_init();
    set_ready_display();
    display_pwm_set_segments(char_led[0], char_led[1], char_led[2]);
    dht22_init();
    ambient_dim_init();
    last_ms = display_pwm_millis();

    while (1) {
        uint16_t now = display_pwm_millis();
        uint16_t dt = (uint16_t)(now - last_ms);

        if (dt > 0U) {
            last_ms = now;
            if (startup_ms < STARTUP_DELAY_MS) {
                startup_ms = (uint16_t)(startup_ms + dt);
            }
            elapsed_since_sample = (uint16_t)(elapsed_since_sample + dt);
            elapsed_in_cycle = (uint16_t)(elapsed_in_cycle + dt);
            if (elapsed_in_cycle >= SAMPLE_PERIOD_MS) {
                elapsed_in_cycle = 0U;
            }
        }

        if (startup_ms >= STARTUP_DELAY_MS &&
            elapsed_since_sample >= SAMPLE_PERIOD_MS) {
            dht22_reading_t reading;

            display_pwm_pause();
            if (dht22_read(&reading) && dht22_reading_is_plausible(&reading)) {
                temperature_tenths_c = reading.temperature_tenths_c;
                humidity_tenths = reading.humidity_tenths;
                have_reading = 1U;
                last_read_failed = 0U;
            } else {
                last_read_failed = 1U;
            }
            display_pwm_resume();

            elapsed_since_sample = 0U;
            elapsed_in_cycle = 0U;
        }

        if (last_read_failed) {
            set_error_display();
        } else if (have_reading) {
            if (elapsed_in_cycle < SHOW_TEMP_MS) {
                set_temperature_display(temperature_tenths_c);
            } else {
                set_humidity_display(humidity_tenths);
            }
        } else {
            set_ready_display();
        }

        display_pwm_set_segments(char_led[0], char_led[1], char_led[2]);
        ambient_dim_update();
        display_pwm_set_brightness(ambient_dim_get_pwm());
    }
}

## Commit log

2015-02-24 Condensed code, added missing IP error handling.
    Condensed code. Python script now sends 255.0.255.0 to the add-on board when no IP address is detected. Once the it is reconnected with the network, the new IP address is sent to the add-on board.
    [hostip.py]
2015-03-01 Change the refresh time
    Changed the refresh time to 2 minutes instead of 10 seconds to send new data to the add-on board less often.
2015-03-03 Fixed a coding mistake.
    Changed sleep time from 5 to refresh constant
    [hostip.py]
2015-03-06 Speed up octet cycling
    Octet cycling was too long. I cut the duration times in half.
    [show_ip.c]
2015-03-11 Show_pi.c count down
    This program proves that the Pi IP Address board was reprogrammed. If it is programmed, the numbers will count down (4,3,2,1) instead of counting up. The IP address will still display the same.
2016-02-11 Correcting IPv6 failures
    I have updated the code because hostname -I caused the script to fail if non-integers were detected in the line. The new way is more robust.
    [hostip.py]
2016-02-27 Corrected Typo
    Changed Most to Least
    [hostip.py]
2016-04-14 Added a way to determine the I2C port
    I included the ability to query the possible I2C ports and see if the Pi IP Address board responds. If it responds, then the I2C port number is assigned.
2016-04-14 Create a cleaner exit when Pi IP board is missing
    [hostip.py]
2016-08-19 Added additional features
    Updated the version to 1.1. The IP address module now displays a power on message and funny timeout message. Additional comments to the code were added for clarity.
2018-11-07 Converted script to Python3
    removed python 2 parts of the script and replaced them with python 3. Also made the script more concise and less redundant.
    [hostip.py]
2026-05-16 Add climate-node-dht22 standalone DHT22 firmware and project docs.
    Introduces ATtiny88 firmware that displays temperature and humidity on the
    existing 7-seg hardware, with Adafruit-style DHT timing, KiCAD assets, deploy
    scripts, and documentation including docs/CLIMATE_NODE.md.
    [Raspberry Pi IP Addr-append-B_Cu.gbl, Raspberry Pi IP Addr-append-B_Mask.gbs, Raspberry Pi IP Addr-append-B_SilkS.gbo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]
2026-05-16 Remove vendored DHT_sensor_library; cite Adafruit upstream in docs.
    Firmware already implements the protocol in src/dht22.c. Drop Arduino
    examples, unified sensor wrapper, and library metadata from the repo.
2026-05-18 Show Err when DHT reads fail after disconnect; slow display timing.
    Display failed reads instead of stale values, use 6 s sample and 3 s
    per field on screen, and update climate node documentation.
    [main.c]
2026-08-28 Add PWM display dimming, calibration offsets, and debug firmware.
    Ambient light sensing on PC1 drives Timer0 PWM brightness; compile-time
    TEMP_OFFSET and HUMIDITY_OFFSET adjust readings; docs cover wiring and tuning.
